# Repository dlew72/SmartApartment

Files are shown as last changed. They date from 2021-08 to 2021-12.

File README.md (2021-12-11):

# SmartApartment

ECE Senior Design Project by Danny Lewis, George Long, Roy Thorstensen, and Olivia Kapp.

Android app was built for Samsung Galaxy S10, but should function on any Android device (Android 6.0+). Volley required.

Smart_Hub_Code, Smart_Light_Code, and Smart_Shade_Code folders contain the code and guides for powering the HUZZAH boards.

KiCadProjects contains the schematics for the devices, as well as the PCB designs.

3DPrints contains STL files for various prints that make up enclosures and supporting peices.

See "Final Report.pdf" (coming soon) for more details on this project and its uses.

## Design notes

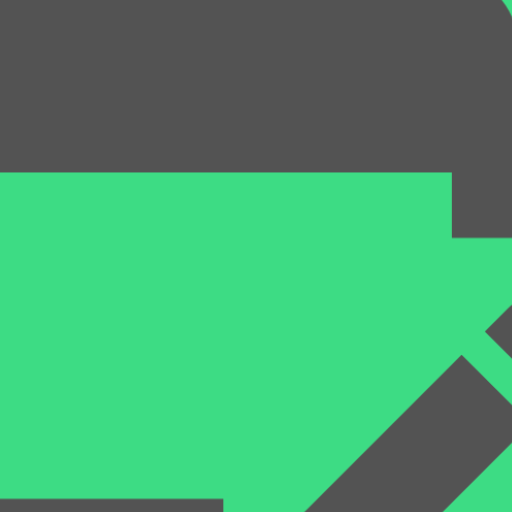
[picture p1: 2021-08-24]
app/src/main/ic_menu_calendar-playstore.png

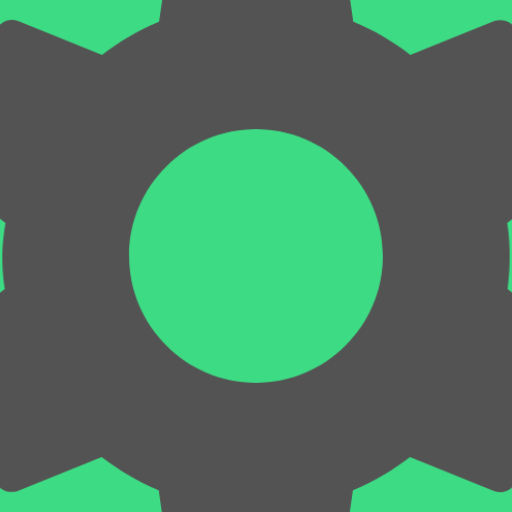
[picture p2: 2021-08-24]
app/src/main/ic_menu_settings-playstore.png

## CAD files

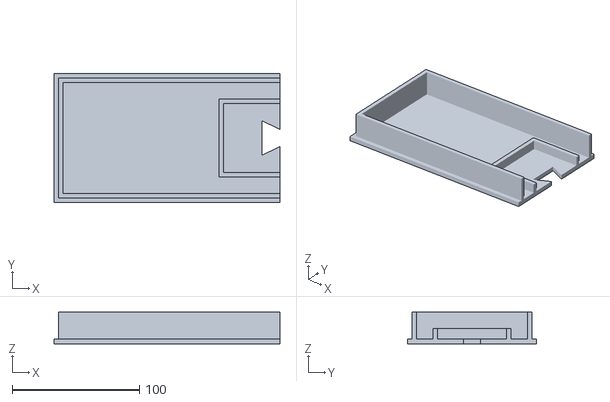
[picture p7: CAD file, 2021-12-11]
3DPrints/Smart_Light_Enclosure_B.stl
177.8 x 101.6 x 25.0

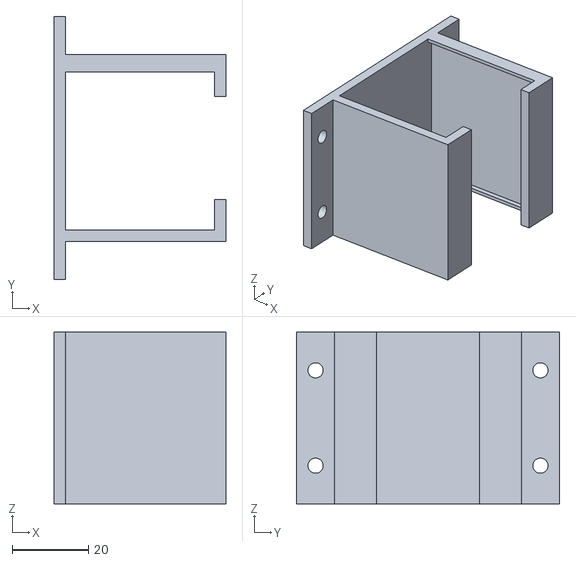
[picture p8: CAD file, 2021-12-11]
3DPrints/Smart_Shade_Motor_Mount.stl
45.0 x 69.0 x 45.0

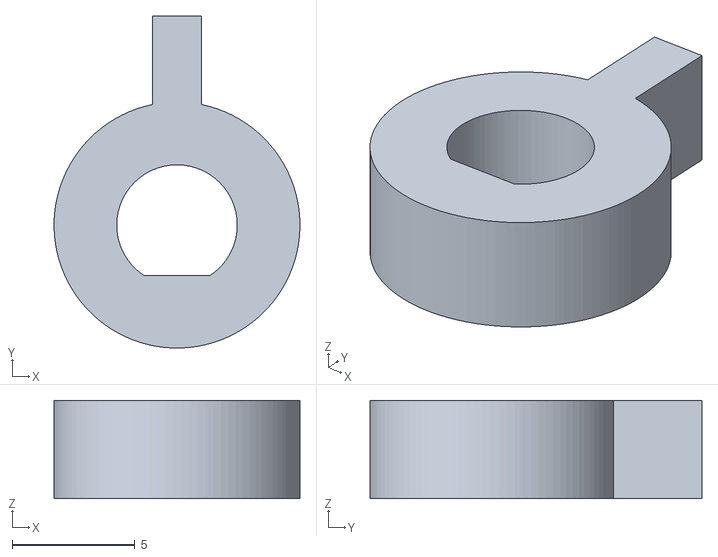
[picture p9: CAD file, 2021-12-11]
3DPrints/Smart_Shade_Motor_Cog.stl
10.00 x 13.5 x 4.00

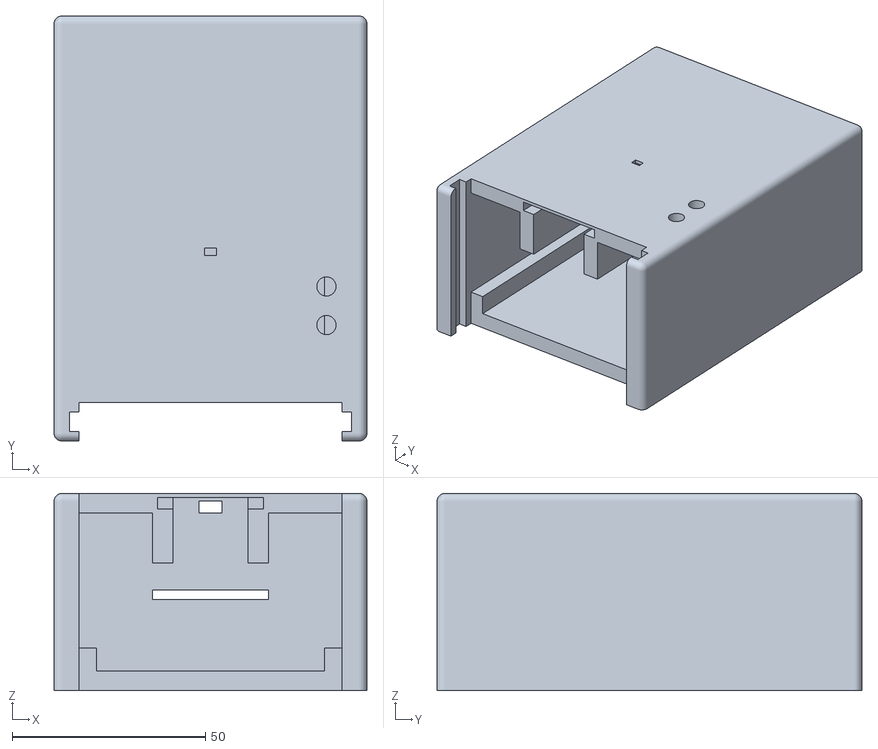
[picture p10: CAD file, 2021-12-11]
3DPrints/Smart_Hub_Body.stl
81.0 x 110.0 x 51.0

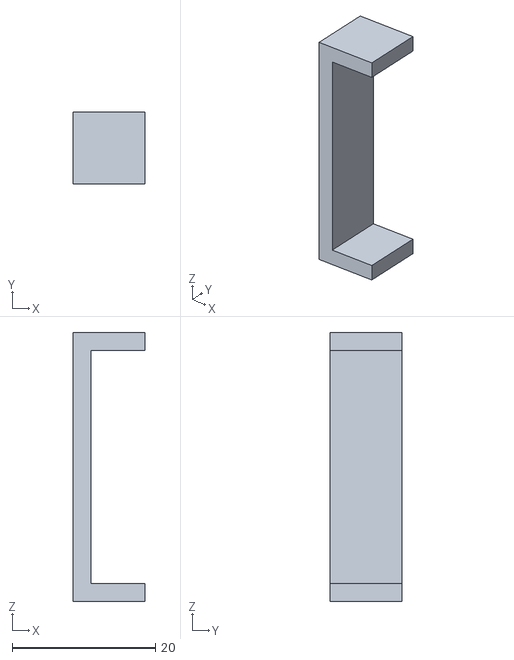
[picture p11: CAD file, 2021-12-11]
3DPrints/Smart_Light_Spacer.stl
10.0 x 10.0 x 37.5

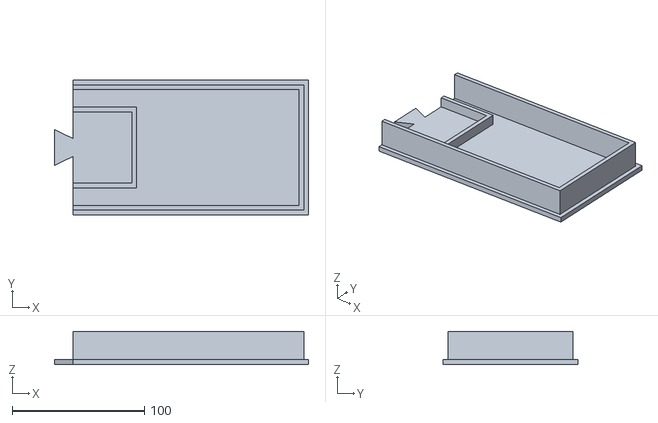
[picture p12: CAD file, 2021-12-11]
3DPrints/Smart_Light_Enclosure_A.stl
191.8 x 101.6 x 25.0

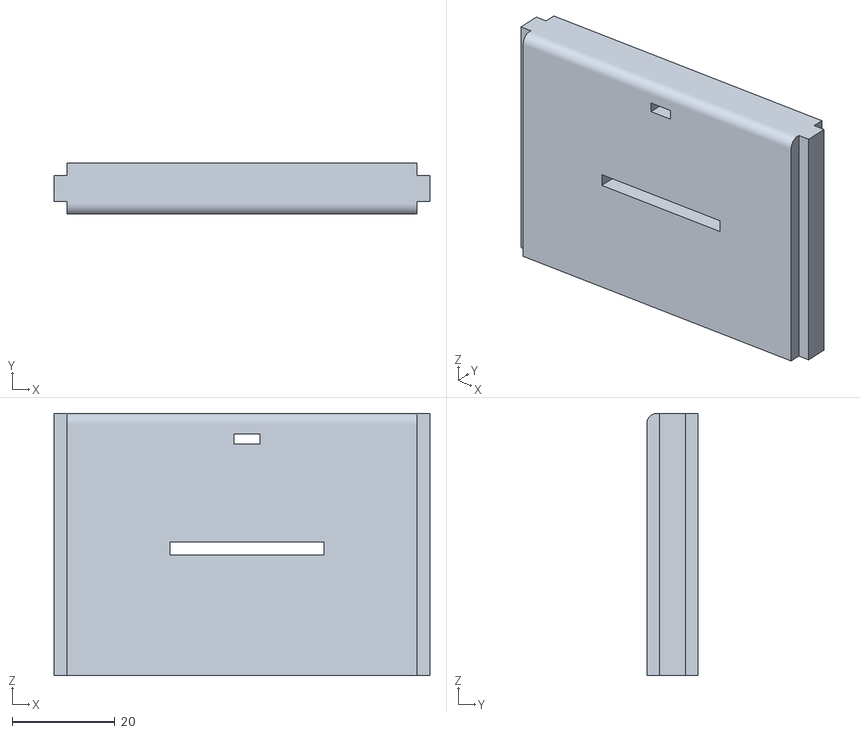
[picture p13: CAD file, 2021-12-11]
3DPrints/Smart_Hub_Gate.stl
73.1 x 10.0 x 51.0

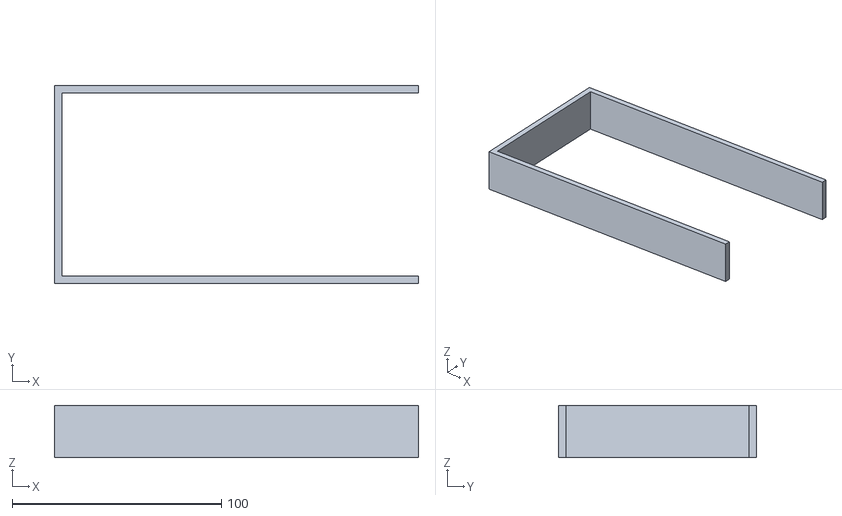
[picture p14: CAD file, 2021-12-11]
3DPrints/Smart_Light_Extension.stl
174.0 x 94.5 x 25.0

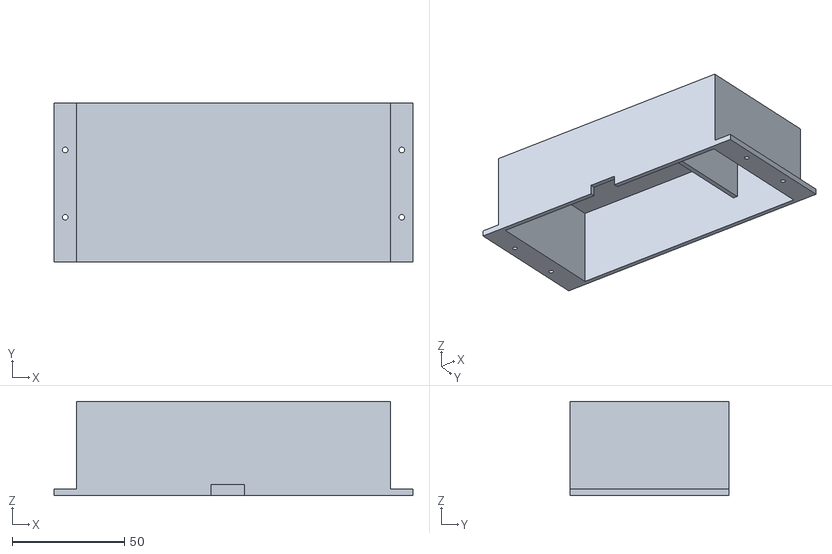
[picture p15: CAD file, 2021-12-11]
3DPrints/Smart_Shade_Motor_Enclosure.stl
160.0 x 71.0 x 42.0

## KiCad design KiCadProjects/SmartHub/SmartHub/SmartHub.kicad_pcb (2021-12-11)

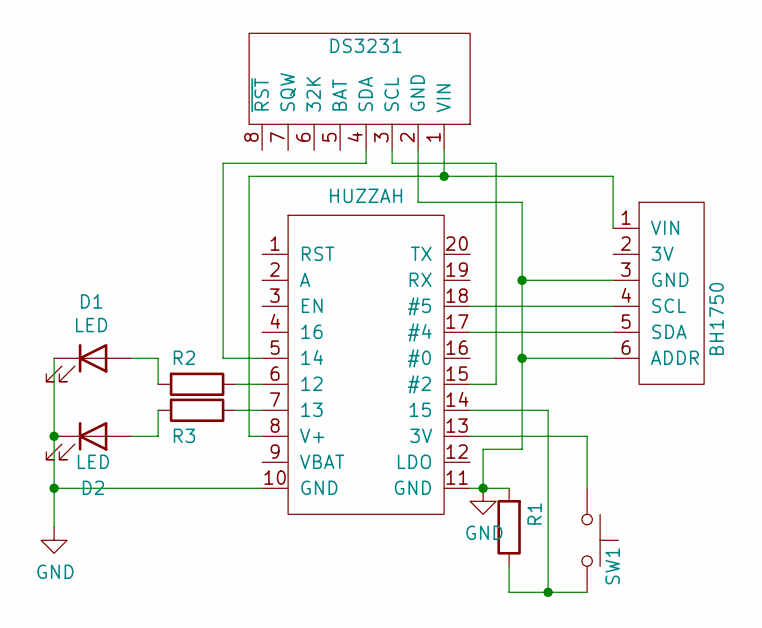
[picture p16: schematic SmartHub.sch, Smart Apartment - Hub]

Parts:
D1, D2: LED; LED_D2.0mm_W4.8mm_H2.5mm_FlatTop
R1, R2, R3: R; R_Axial_DIN0207_L6.3mm_D2.5mm_P10.16mm_Horizontal
SW1: SW_Push; R_Axial_DIN0204_L3.6mm_D1.6mm_P5.08mm_Horizontal
U1: DS3231; DS3231_FOOT
U2: BH1750; BH1750_BO_FOOT
u1: HUZZAH; HUZZAH_FOOT

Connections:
GND: D1.1 (K), D2.1 (K), R1.2, U1.2 (GND), U2.3 (GND), U2.6 (ADDR), u1.10 (GND), u1.11 (GND)
unnamed: D1.2 (A), R2.2
unnamed: D2.2 (A), R3.2
unnamed: R1.1, SW1.2, u1.14 (15)
unnamed: R2.1, u1.6 (12)
unnamed: R3.1, u1.7 (13)
unnamed: SW1.1, u1.13 (3V)
unnamed: U1.1 (VIN), U2.1 (VIN), u1.8 (V+)
unnamed: U1.3 (SCL), u1.15 (#2)
unnamed: U1.4 (SDA), u1.5 (14)
unnamed: U2.4 (SCL), u1.18 (#5)
unnamed: U2.5 (SDA), u1.17 (#4)

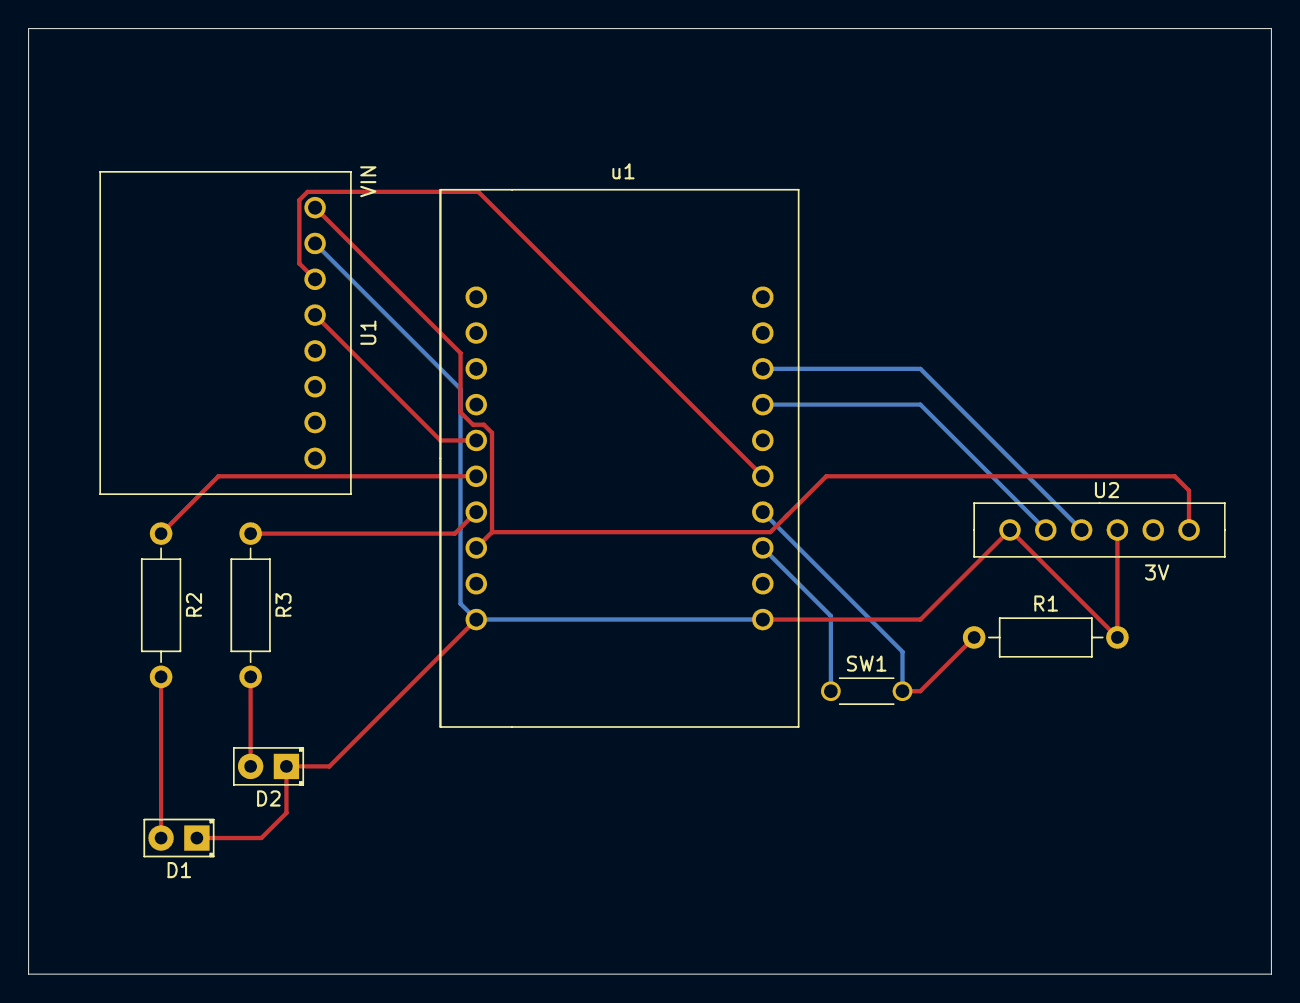
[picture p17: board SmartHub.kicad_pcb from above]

Board: 2 copper layers, 88.1 x 67.1 mm, 9 parts (0 on the bottom side), 12 nets.

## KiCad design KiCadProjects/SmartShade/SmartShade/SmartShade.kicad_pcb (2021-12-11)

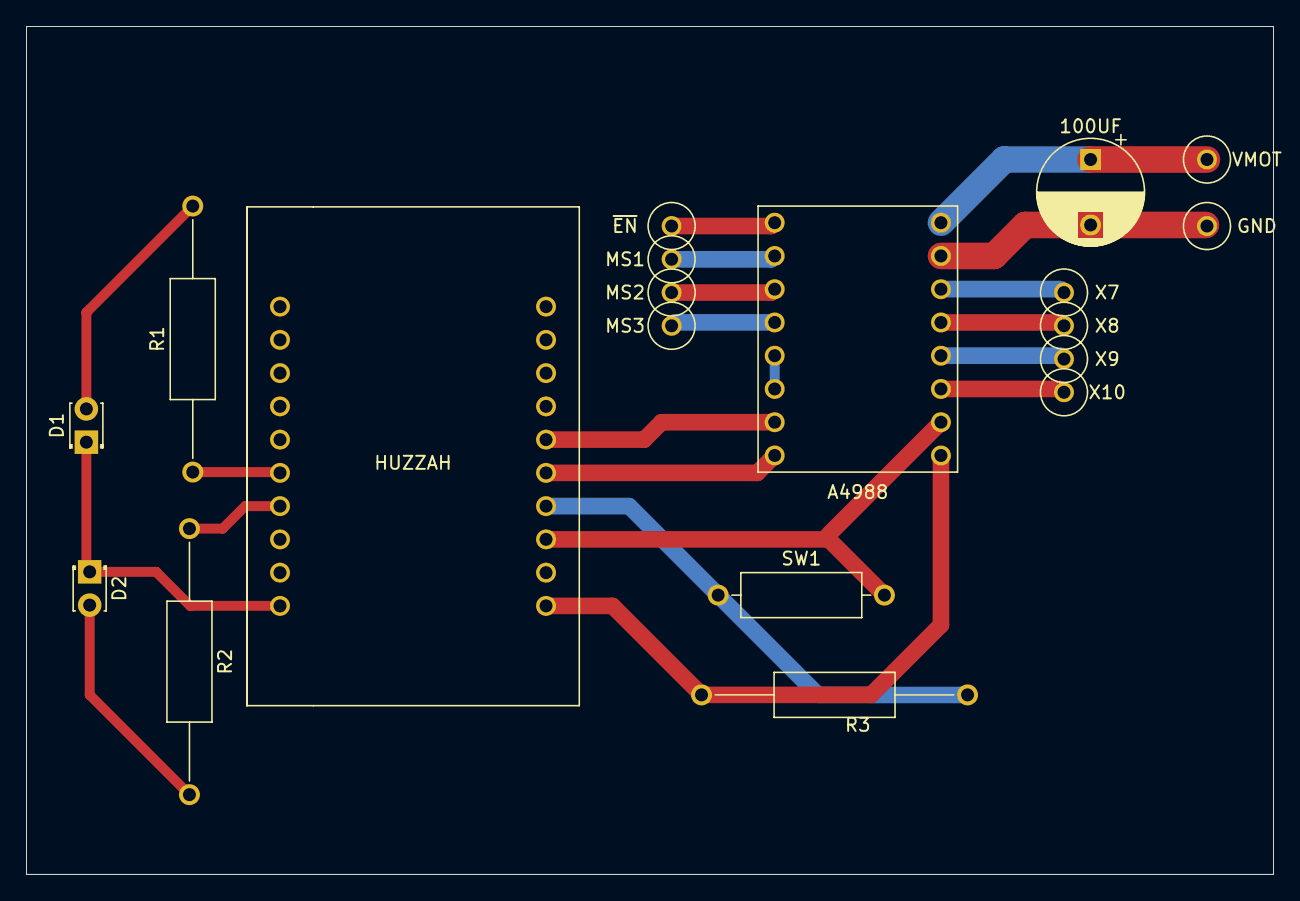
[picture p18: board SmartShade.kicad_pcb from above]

Board: 2 copper layers, 95.2 x 64.8 mm, 18 parts (0 on the bottom side), 20 nets.

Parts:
100UF: CP; CP_Radial_D8.0mm_P5.00mm
A4988: A4988; a4988_foot
D1, D2: LED; LED_D1.8mm_W3.3mm_H2.4mm
GND: Pad; Pad_FOOT
HUZZAH: HUZZAH; HUZZAH_FOOT
MS1, MS2, MS3: Pad; Pad_FOOT
R1, R2, R3: R; R_Axial_DIN0309_L9.0mm_D3.2mm_P20.32mm_Horizontal
SW1: SW_Push; R_Axial_DIN0309_L9.0mm_D3.2mm_P12.70mm_Horizontal
VMOT: Pad; Pad_FOOT
X7, X8, X9, X10: Pad; Pad_FOOT

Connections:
unnamed: 100UF.1, A4988.16, VMOT.1
unnamed: 100UF.2, A4988.15, GND.1
unnamed: D1.1, D2.1, HUZZAH.10
unnamed: D1.2, R1.2
unnamed: D2.2, R2.2
unnamed: HUZZAH.6, R1.1
unnamed: HUZZAH.7, R2.1
unnamed: A4988.9, HUZZAH.11, R3.1
unnamed: HUZZAH.14, R3.2, SW1.2
unnamed: A4988.10, HUZZAH.13, SW1.1
unnamed: A4988.2, MS1.1
unnamed: A4988.3, MS2.1
unnamed: A4988.4, MS3.1
unnamed: A4988.5, A4988.6
unnamed: A4988.7, HUZZAH.16
unnamed: A4988.8, HUZZAH.15
unnamed: A4988.11, X10.1
unnamed: A4988.12, X9.1
unnamed: A4988.13, X8.1
unnamed: A4988.14, X7.1

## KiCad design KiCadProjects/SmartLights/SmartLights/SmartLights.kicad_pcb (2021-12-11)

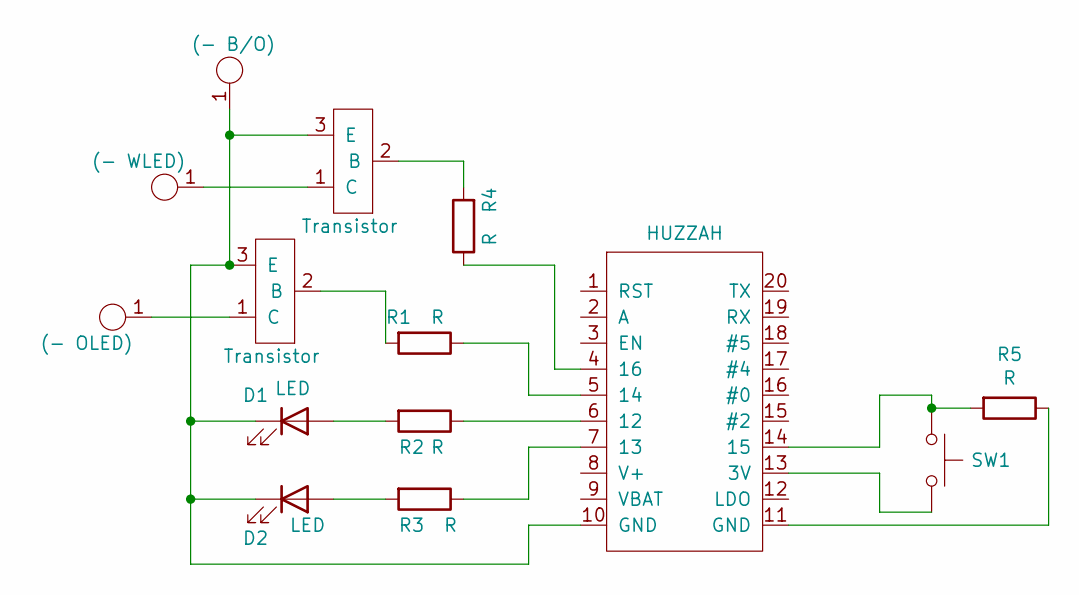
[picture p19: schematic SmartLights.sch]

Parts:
D1, D2: LED; LED_D2.0mm_W4.8mm_H2.5mm_FlatTop
Q1, Q2: Transistor; Transistor_FOOT
R1, R2, R3, R4, R5: R; R_Axial_DIN0207_L6.3mm_D2.5mm_P10.16mm_Horizontal
SW1: SW_Push; R_Axial_DIN0207_L6.3mm_D2.5mm_P10.16mm_Horizontal
X1: (- OLED); Pad_FOOT
X2: (- WLED); Pad_FOOT
X3: (- B/O); Pad_FOOT
u1: HUZZAH; HUZZAH_FOOT

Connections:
unnamed: D1.1 (K), D2.1 (K), Q1.3 (E), Q2.3 (E), X3.1, u1.10 (GND)
unnamed: D1.2 (A), R2.2
unnamed: D2.2 (A), R3.2
unnamed: Q1.1 (C), X1.1
unnamed: Q1.2 (B), R1.2
unnamed: Q2.1 (C), X2.1
unnamed: Q2.2 (B), R4.2
unnamed: R1.1, u1.5 (14)
unnamed: R2.1, u1.6 (12)
unnamed: R3.1, u1.7 (13)
unnamed: R4.1, u1.4 (16)
unnamed: R5.1, u1.11 (GND)
unnamed: R5.2, SW1.1, u1.14 (15)
unnamed: SW1.2, u1.13 (3V)

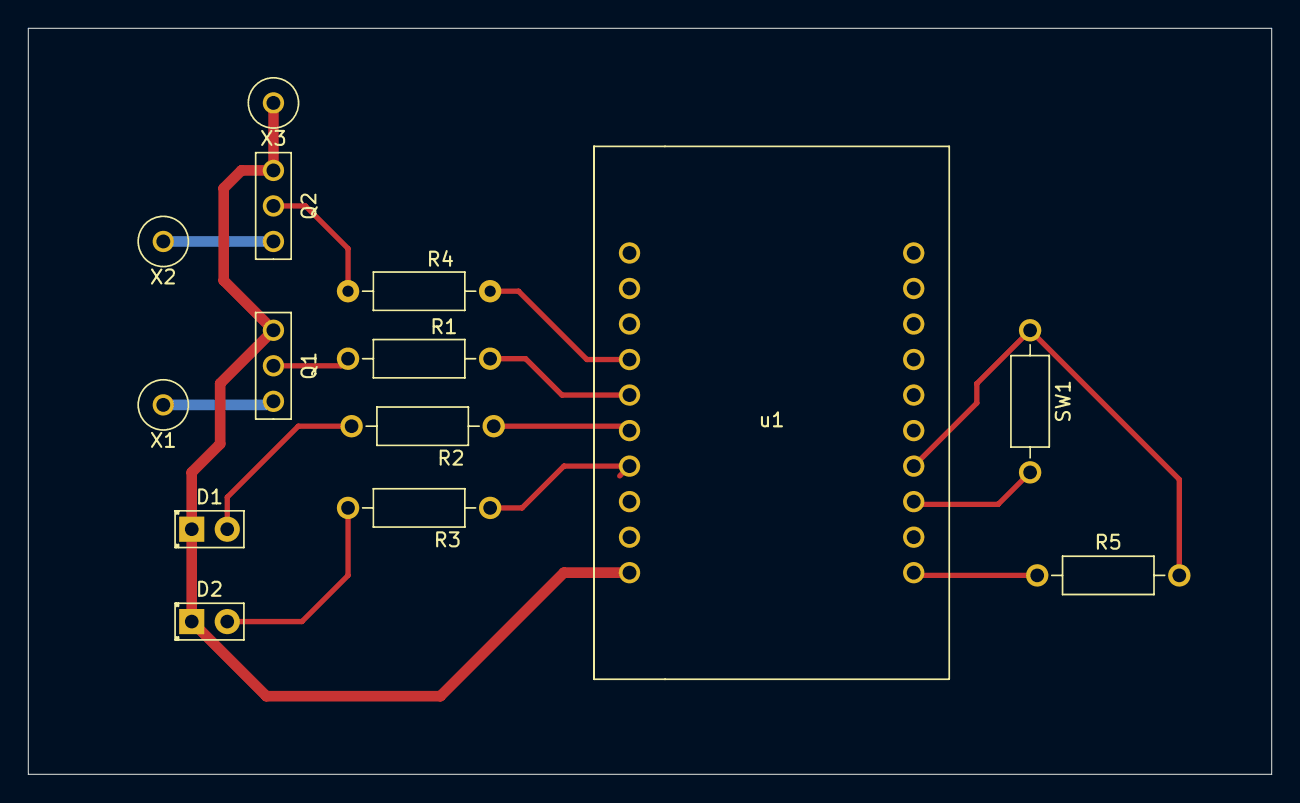
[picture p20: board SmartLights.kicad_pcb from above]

Board: 2 copper layers, 88.9 x 53.3 mm, 14 parts (0 on the bottom side), 14 nets.

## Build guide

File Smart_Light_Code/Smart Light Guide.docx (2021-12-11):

Smart Light Guide

EEPROM Guide:

Addr. | 0 | 1 | 2 | 3 | 4 | 5 | 6 | 7 | 8 | 9 | 10 | 11 | … | 128 | 164
Val. | Valid Cred? | SSID Len. | SSID | | | | Pass Len. | Password | | | | | … | B | W
Ex. | 7 | 4 | s | s | i | d | 5 | p | a | s | s | w | … | 50 | 75

- Address 0 represents whether or not the Light has valid network credentials stored
  - A value of 7 causes the Light to repeatedly try to connect to the network
  - Any other value causes the Light to enter setup mode
- Address 1 holds the amount of characters in the SSID (n)
- Addresses 2 → n + 1 hold the SSID
- Address n+2 holds the amount of characters in the password (m)
- Addresses n+3 → m+n+2 hold the password
- Address 128 holds the current brightness of the light (0-100%)
- Address 164 holds the current warmth value of the light (0-100%)

Indicator Light Guide:

Red LED State | Green LED State | Device Status
Off | Off | Powered Off
Flashing | Off | Searching for Hub AP (setup mode)
Solid | Off | Connected to Hub AP
Solid | Flashing | Attempting Connection to Home Network
Solid | Solid | Connected to Home Network

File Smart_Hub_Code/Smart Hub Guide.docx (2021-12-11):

Smart Hub Guide

EEPROM Guide:

Addr. | 0 | 1 | 2 | 3 | 4 | 5 | 6 | 7 | 8 | 9 | 10 | 11 | 12 | 13 | 14
Val. | Valid Cred? | SSID Len. | SSID | | | | Pass Len. | Password | | | | | B | W | Pos
Ex. | 7 | 4 | s | s | i | d | 5 | p | a | s | s | w | 95 | 100 | 20

- Address 0 represents whether or not the hub has valid network credentials stored
  - A value of 7 causes the hub to repeatedly try to connect to the network
  - Any other value causes the hub to enter setup mode
- Address 1 holds the amount of characters in the SSID (n)
- Addresses 2 → n + 1 hold the SSID
- Address n+2 holds the amount of characters in the password (m)
- Addresses n+3 → m+n+2 hold the password
- Address m+n+3 holds the current brightness of the lights (0-100%)
- Address m+n+4 holds the current warmth value of the lights (0-100%)
- Address m+n+5 holds the current position value of the shade (0-100%)

Addr. | 129 | 130 | 131 | 132 | 133 | 134 | 135 | 136 | 137 | 138 | 139 | 140 | 141
Val. | DoW | Hour | Min. | Type | Par. 1 | Par. 2 | DoW | Hour | Min | Type | Par. 1 | Par. 2 | End
Ex. | N | 9 | 30 | L | 50 | 100 | S | 10 | 45 | S | 100 | 0 | X
Type | Char | Int | Int | Char | Int | Int | Char | Int | Int | Char | Int | Int | Char

- Address 129 marks the start of scheduling data
  - Scheduled actions are stored as chunks of data 6 addresses wide
  - Address 129 marks the day of the week (encoded as a character)
    - N M T W R F A
  - Address 130 holds the hour (military time)
  - Address 131 hold the minute
  - Address 132 holds the device that the action is meant for (L or S – Lights or Shade)
  - Address 133 holds Parameter 1 (Brightness or Position)
  - Address 134 holds Parameter 2 (Warmth)
  - Addresses 135-140 hold the same info in the same order for a differently scheduled action
  - Pattern continues indefinitely until an X is stored in the address immediately following the last scheduled action

Indicator Light Guide:

Red LED State | Green LED State | Device Status
Off | Off | Powered Off
Solid | Off | On, broadcasting AP (setup mode)
Solid | Flashing | Attempting Connection to Home Network
Solid | Solid | Connected to Home Network

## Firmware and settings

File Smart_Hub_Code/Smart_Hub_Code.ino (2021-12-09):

#include <ESP8266WiFi.h>
#include <WiFiClient.h>
#include <ESP8266WiFiMulti.h> 
#include <ESP8266HTTPClient.h>
#include <ESP8266LLMNR.h>
#include <ESP8266WebServer.h>   // Include the WebServer library
#include <EEPROM.h>
#include "RTClib.h"
#include <Wire.h>
#include <BH1750.h>

BH1750 lightMeter;

ESP8266WebServer server(80);    // Create a webserver object that listens for HTTP request on port 80

//EEPROM Address index
int addr = 0;

//to ensure schedule is only checked once a minute
int prevMin = -1;

//RTC
RTC_DS3231 rtc;

//RTC comparison helper
char daysOfTheWeek[] = {'U', 'M', 'T', 'W', 'R', 'F', 'A'};

struct action {
  char dow;
  int h;
  int m;
  char type;
  int par1;
  int par2;
};

//setup or operation flag
bool operationMode = false;

//pin assignments
int greenLEDpin = 12;
int redLEDpin = 13;
int hardResetButton = 15;

//hardcoded peripheral IPs
String shadeServerIP = "http://192.168.0.178/";
String shadeServerIPSetup = "http://192.168.4.178/";

String lightServerIP = "http://192.168.0.179/";
String lightServerIPSetup = "http://192.168.4.179/";


// function prototypes for HTTP handlers
void handleRoot();              
void handleNotFound();
void handleSchedule();
void handleAction();
void handleGetState();
void handleBrightness();

// misc function prototypes
void hubSetupMode();
void connectToSavedNetwork();
void readEEPROM();
void wipeEEPROM();
void shareCredentials(String, String);
bool checkSchedValid();
void checkSchedule(DateTime);
String getLightState();
String getShadeState();
void handleBrightness();

//Interrupt
ICACHE_RAM_ATTR void resetButtonPressed();

// software reset function
void(* resetFunc) (void) = 0;

void setup()
{
  Serial.begin(19200);
  Serial.println("Fresh Run");
  EEPROM.begin(1024);
  Wire.begin(14, 2);
  rtc.begin();

  //set pinmodes
  pinMode(greenLEDpin, OUTPUT);
  pinMode(redLEDpin, OUTPUT);
  pinMode(hardResetButton, INPUT);

  //set up interrupt
  attachInterrupt(digitalPinToInterrupt(hardResetButton), resetButtonPressed, RISING);

  //set power indicator on
  digitalWrite(redLEDpin, HIGH);

  //check if setup byte is set
  if (EEPROM.read(0) == char(7)) {
    //hub was already configured. attempt to connect to network
    connectToSavedNetwork();    
    operationMode = true;
  }
  else {
    //No saved credentials. Enter setup mode
    hubSetupMode();
  }

  //HTTP handlers
  server.on("/", handleRoot);                      // Call the 'handleRoot' function when a client requests URI "/"
  server.on("/credentials", handleCredentials);    // Call the 'handleCredentials' function when a client requests URI "/credentials"
  server.on("/getStates", handleGetState);
  server.on("/brightness", handleBrightness);
  server.on("/schedule", handleSchedule);       // Call the 'handleSchedule' function when a client requests URI "/schedule"
  server.on("/action", handleAction);         // Call the 'handleAction' function when a client requests URI "/action"
  server.onNotFound(handleNotFound);        // When a client requests an unknown URI (i.e. something other than "/"), call function "handleNotFound"

// Actually start the server
  server.begin();                           
  Serial.println("HTTP server started");
}

void loop()
{
  server.handleClient();
  digitalWrite(redLEDpin, HIGH);
  if (operationMode)
    digitalWrite(greenLEDpin, HIGH);
  else
    digitalWrite(greenLEDpin, LOW);

  Wire.begin(14, 2);
  rtc.begin();
  DateTime now = rtc.now();
  if (prevMin != now.minute()) {
    Serial.print("Prevmin:");
    Serial.println(prevMin);
    Serial.print("nowmin:");
    Serial.println(now.minute());
    prevMin = now.minute();
    checkSchedule(now);
  }
}


bool checkSchedValid() {
  addr = 129;
  if (char(EEPROM.read(addr)) == 'U' || char(EEPROM.read(addr)) == 'M' || char(EEPROM.read(addr)) == 'T' || char(EEPROM.read(addr)) == 'W' || char(EEPROM.read(addr)) == 'R' || char(EEPROM.read(addr)) == 'F' || char(EEPROM.read(addr)) == 'A')
    return true;
  return false;
}

void checkSchedule(DateTime now) {
  Serial.println("Checking Schedule...");

   if (!checkSchedValid()) {
    Serial.println("SCHEDULE NOT VALID...");
    return;
   }
   else {
    Serial.println("Schedule Valid!!");
   }
        
   addr = 129;
   action myAct = {char(EEPROM.read(addr)), int(EEPROM.read(addr+1)), int(EEPROM.read(addr+2)), char(EEPROM.read(addr+3)), int(EEPROM.read(addr+4)), int(EEPROM.read(addr+5))};
   while (myAct.dow != 'X') {
      //Check day of week, then hour, then minute
      //If all match, send action and add action addr to recent list
      if (daysOfTheWeek[now.dayOfTheWeek()] == myAct.dow && now.hour() == myAct.h+1 && now.minute() == myAct.m) {
        Serial.println("SENDING ACTION!");
        //Everything matched! Send the action
        if (myAct.type == 'L')
          sendAction(lightServerIP, myAct.par1, myAct.par2);
        if (myAct.type == 'S')
          sendAction(shadeServerIP, myAct.par1, myAct.par2);
     }  
     //go to next action
     addr += 6;
     myAct = {char(EEPROM.read(addr)), int(EEPROM.read(addr+1)), int(EEPROM.read(addr+2)), char(EEPROM.read(addr+3)), int(EEPROM.read(addr+4)), int(EEPROM.read(addr+5))};
   }
}

void handleRoot() {
  Serial.println("ROOT");
  server.send(200, "text/plain", "Hello world 123!");   // Send HTTP status 200 (Ok) and send some text to the browser/client
}

void handleCredentials() {
  Serial.println("CREDENTIALS");
  if (server.hasArg("plain")== false){ //Check if body received
         server.send(400, "text/plain", "fail");
         return;
      }
      
      server.send(200, "text/plain", "success");

      /** the current address in the EEPROM (i.e. which byte we're going to write to next) **/
      addr = 0;
      EEPROM.put(addr, char(7));
      addr++;
      
      String message = server.arg("plain");
      
      String username = message.substring(9, message.indexOf("\",\"p$$$\":\""));

      String password = message.substring(message.indexOf("p$$$")+7, message.length()-2);

      EEPROM.put(addr, username.length());
      addr++;

      for (int i = 0; i < username.length(); i++) {
         EEPROM.put(addr, username[i]);
         addr++;
      }

      EEPROM.put(addr, password.length());
      addr++;

      for (int i = 0; i < password.length(); i++) {
         EEPROM.put(addr, password[i]);
         addr++;
      }

      EEPROM.commit();

      //Share credentials with lights and shade
      shareCredentials(username, password);

      //Try to use credentials to connect:
      WiFi.mode(WIFI_STA);
      IPAddress ip(192, 168, 0, 177);
      IPAddress dns(192, 168, 0, 1);
      IPAddress gateway(192, 168, 0, 1);
      IPAddress subnet(255, 255, 255, 0);
      WiFi.config(ip, dns, gateway, subnet);
      WiFi.begin(username, password);
      unsigned long timeOfStartConnection = millis();
  
      while (1) {
        yield();
        if (WiFi.status() == WL_CONNECTED) {
          //We connected to the router
          operationMode = true;
          break;
        }
        if (millis() - timeOfStartConnection > 10000) {
          //connection failed (timeout)
          break;
        }
        digitalWrite(redLEDpin, !digitalRead(redLEDpin));
        delay(500);
      }

      if (!operationMode) {
        //credentials failed. wipe EEPROM(0) and reset.
        EEPROM.write(0, 0);
        EEPROM.commit();
        Serial.println("RESETTING...");
        resetFunc();
      }
}

void handleNotFound(){
    Serial.println("NOT FOUND");
  server.send(404, "text/plain", "404: Not found"); // Send HTTP status 404 (Not Found) when there's no handler for the URI in the request
}

void handleSchedule() {
  Serial.println("SCHEDULE DETECTED");
  if (server.hasArg("plain")== false){ //Check if body received
           server.send(400, "text/plain", "fail");
           Serial.println("400 fail");
           return;
    }
    
    server.send(200, "text/plain", "success");

    String message = server.arg("plain");

    message = message.substring(13, message.length()-2);

    int numberSchedules = message.length()/12;

//"M0830L100000X"
    addr = 129;
    String temp = "";
    String finalThing = "";
    for (int action = 0; action < numberSchedules; action++) { 
      
      finalThing = message[action*12];
      EEPROM.put(addr, message[action*12]);
      addr++;
      
      temp = message[action*12 + 1];
      temp.concat(message[action*12+2]);
      finalThing += temp.toInt();
      EEPROM.put(addr, temp.toInt());
      addr++;
      
      temp = message[action*12 + 3];
      temp.concat(message[action*12+4]);
      finalThing += temp.toInt();
      EEPROM.put(addr, temp.toInt());
      addr++;
      
      finalThing += message[action*12 + 5];
      EEPROM.put(addr, message[action*12 + 5]);
      addr++;
      
      temp = message[action*12 + 6];
      temp.concat(message[action*12+7]);
      temp.concat(message[action*12+8]);
      finalThing += temp.toInt();
      EEPROM.put(addr, temp.toInt());
      addr++;
      
      temp = message[action*12 + 9];
      temp.concat(message[action*12+10]);
      temp.concat(message[action*12+11]);
      finalThing += temp.toInt();
      EEPROM.put(addr, temp.toInt());
      addr++;
    }

    for (int i = 0; i < 13; i++) {
      EEPROM.put(addr, 'X');
      addr++;
    }
    EEPROM.commit();
    //readEEPROM();
}

void handleAction(){
    Serial.println("ACTION DETECTED");
    
    if (server.hasArg("plain")== false){ //Check if body received
           server.send(400, "text/plain", "fail");
           Serial.println("400 fail");
           return;
    }
    
    server.send(200, "text/plain", "success");

    String message = server.arg("plain");

    Serial.println("MESSAGE:");
    Serial.println(message);

    if (message.substring(2, 6) != "a###") {
           server.send(400, "text/plain", "invalid syntax");
           Serial.println("400 syntax fail");
           return;
    }
 
    String actionString = message.substring(9, message.length()-2);
        //SAMPLE
        // N0930L050100
        // X0000L050100
    if (actionString[5] == 'L') {
      //send to lights
      sendAction(lightServerIP, actionString.substring(6, 9).toInt(), actionString.substring(9).toInt());
    }
    if (actionString[5] == 'S') {
      //send to shade
      sendAction(shadeServerIP, actionString.substring(6, 9).toInt(), 0);
    }
}

void sendAction(String ip, int p1, int p2) {
  digitalWrite(greenLEDpin, LOW);
  WiFiClient cli;
  HTTPClient http;
  int httpResponseCode;

  http.begin(cli, ip + "action");

  http.addHeader("Content-Type", "text/plain");

  httpResponseCode = http.POST("#" + String(p1) + "$" + String(p2));      
  Serial.print("HTTP Response code: ");
  Serial.println(httpResponseCode);

  http.end();

  digitalWrite(greenLEDpin, HIGH);

}

void wipeEEPROM() {
  EEPROM.write(0, char(0));
  EEPROM.commit();
}

void readEEPROM() {
  for (int i = 0; i < 256; i++) {
     Serial.print("i = ");
     Serial.print(i);
     Serial.print(": ");
     Serial.print(int(EEPROM.read(i)));
     Serial.print(", ");
     Serial.print(char(EEPROM.read(i)));

     Serial.print("\n");
  }
}

void hubSetupMode() {
    Serial.print("Setting soft-AP ... ");
    boolean result = WiFi.softAP("ECE Smart Hub", "seniordesign");
    if(result == true)
    {
      Serial.println("Ready");
      LLMNR.begin("esp8266");
      Serial.println("LLMNR responder started");
    }
  else
    Serial.println("Failure to set up Soft-AP");
}

void connectToSavedNetwork() {
    //Supposedly set up already. Try connecting to network
    String ssid = "";
    String password = "";
    int ssidLen = int(EEPROM.read(1));
    int passwordLen = int(EEPROM.read(2+ssidLen));

    //Serial.println("ssid:");
    for (int i = 0; i < ssidLen; i++) {
      ssid += char(EEPROM.read(2+i));
      //Serial.print(char(EEPROM.read(2+i)));
    }
    
    //Serial.println("pass:");
    for (int i = 0; i < passwordLen; i++) {
      password += char(EEPROM.read(3+i+ssidLen));
      //Serial.print(char(EEPROM.read(3+i+ssidLen)));
    }

    //Serial.println("Password: " + password);

    //Hardcode IP data for now
    IPAddress ip(192, 168, 0, 177);
    IPAddress dns(192, 168, 0, 1);
    IPAddress gateway(192, 168, 0, 1);
    IPAddress subnet(255, 255, 255, 0);

    //Configure WiFi with above parameters
    WiFi.config(ip, dns, gateway, subnet);

    //Attempt connection
    WiFi.mode(WIFI_STA);
    WiFi.begin(ssid, password);
    
    while (WiFi.status() != WL_CONNECTED) {
      //While we aren't connected, flash red indicator light 
        digitalWrite(redLEDpin, !digitalRead(redLEDpin));
        delay(500);
    }
    //Now we are connected to the saved AP.
}

void handleGetState() {
  Serial.println("Handling GET STATE");
  //App requests current device values to initialize sliders on dashboard

  String lightState = getLightState();
  String shadeState = getShadeState();
  
  //respond
  String states = "L:" + String(lightState) + "S:" + String(shadeState);
  server.send(200, "text/plain", states);
}

String getLightState() {
  WiFiClient cli;
  HTTPClient http;
  int httpResponseCode;

  http.begin(cli, lightServerIP + "getState");

  http.addHeader("Content-Type", "text/plain");

  httpResponseCode = http.GET();      
  Serial.print("HTTP Response code: ");
  Serial.println(httpResponseCode);

  String message = http.getString();

  Serial.println("MESSAGE:");
  Serial.println(message);

  http.end();

  return message;
}

String getShadeState() {
  WiFiClient cli;
  HTTPClient http;
  int httpResponseCode;

  http.begin(cli, shadeServerIP + "getState");

  http.addHeader("Content-Type", "text/plain");

  httpResponseCode = http.GET();      
  Serial.print("HTTP Response code: ");
  Serial.println(httpResponseCode);
  
  String message = http.getString();
  
  http.end();

  return message;
}

void handleBrightness() {
  Wire.begin(4, 5);
  delay(1);
  lightMeter.begin();
  Serial.print("We are where we think we are");
  float lux = lightMeter.readLightLevel();
  Serial.print("Light: ");
  Serial.print(lux);

  server.send(200, "text/plain", String(lux));
}

void shareCredentials(String ssid, String pass) {

  WiFiClient cli;
  HTTPClient http;
  int httpResponseCode;

  http.begin(cli, shadeServerIPSetup + "credentials");

  http.addHeader("Content-Type", "text/plain");

  httpResponseCode = http.POST(ssid + ":d@nnyl3w!$@%!$@@:" + pass);      
  Serial.print("HTTP Response code: ");
  Serial.println(httpResponseCode);

  http.end();

  delay(500);

  http.begin(cli, lightServerIPSetup + "credentials");

  http.addHeader("Content-Type", "text/plain");

  httpResponseCode = http.POST(ssid + ":d@nnyl3w!$@%!$@@:" + pass);      
  Serial.print("HTTP Response code: ");
  Serial.println(httpResponseCode);

  http.end();
}

ICACHE_RAM_ATTR void resetButtonPressed() {
    Serial.println("WIPING EEPROM");
    wipeEEPROM();
    resetFunc();
}

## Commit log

2021-08-24 add checkConnection logic / flow
2021-09-27 setup flow (hub only) complete
2021-09-29 Created smart hub guide -- currently includes memory maps
2021-10-19 settings implemented in app interrupts implemented in all devices sync schedule routine begun
2021-10-19 schedule receives, but is not parsed correctly
    [Smart_Hub_Code.ino]
2021-12-10 resolve differences between double light file
    [Smart_Light_Code.ino]
2021-12-11 add KiCad files
    [SmartHub-B_Cu.gbr, SmartHub-B_Mask.gbr, SmartHub-B_Paste.gbr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]
2021-12-11 add 3D models (stls)
    [Smart_Hub_Body.stl, Smart_Hub_Gate.stl, Smart_Light_Enclosure_A.stl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]
